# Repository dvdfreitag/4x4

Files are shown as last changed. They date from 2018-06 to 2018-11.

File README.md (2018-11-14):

# 4x4
A 4x4 mechanical keyboard

More or less a clone of https://github.com/di0ib/Misc/tree/master/4x4, but with a different controller. An Arduino Pro Micro instead of an Arduino Micro, they're much easier to get.





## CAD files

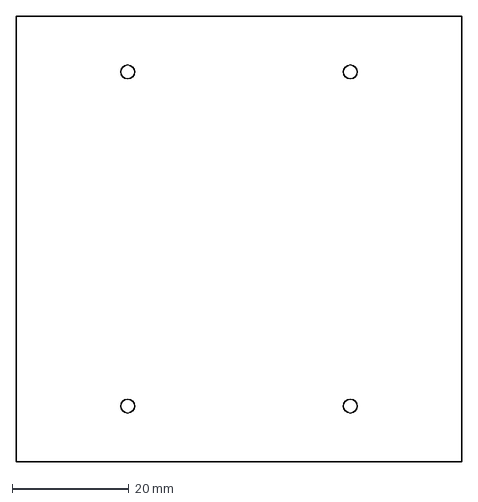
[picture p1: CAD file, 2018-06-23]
4x4-keyboard.dxf
76.2 x 76.2 mm

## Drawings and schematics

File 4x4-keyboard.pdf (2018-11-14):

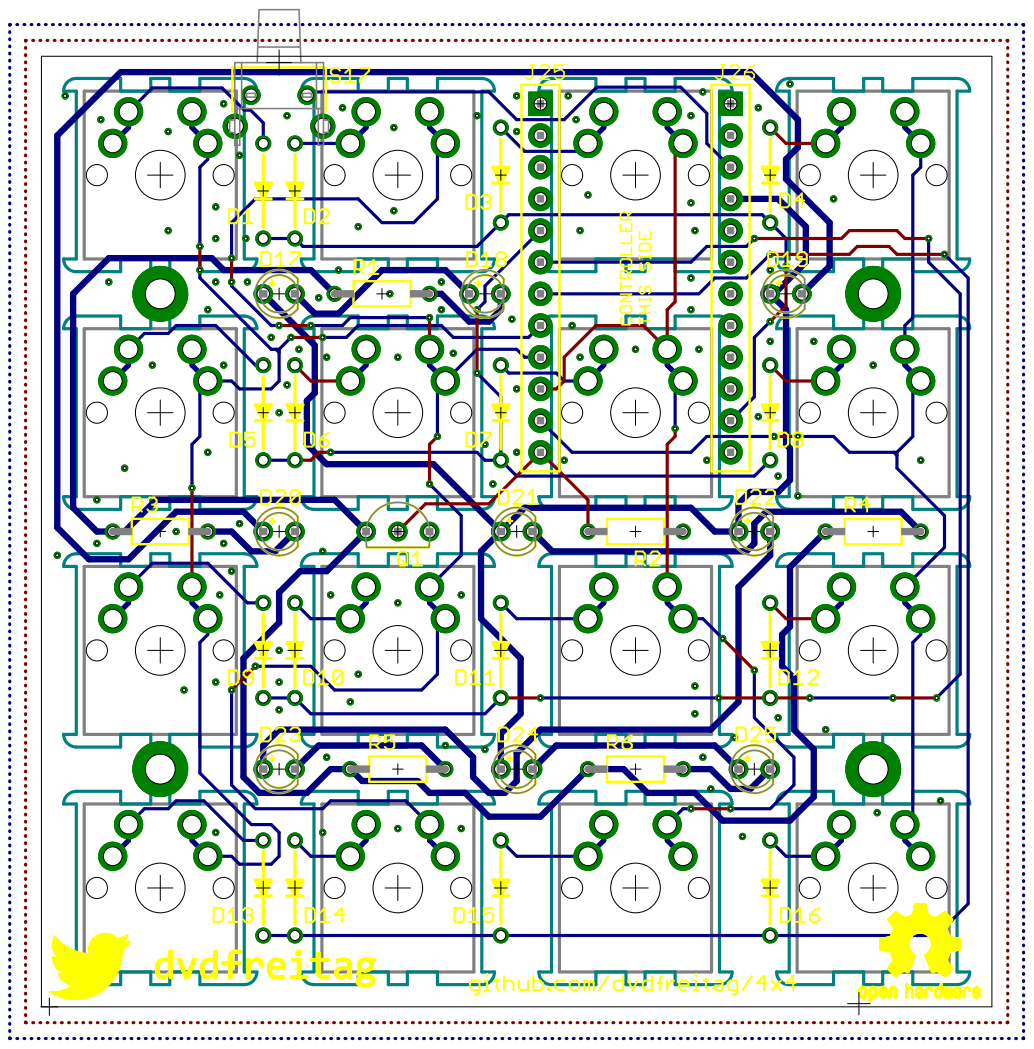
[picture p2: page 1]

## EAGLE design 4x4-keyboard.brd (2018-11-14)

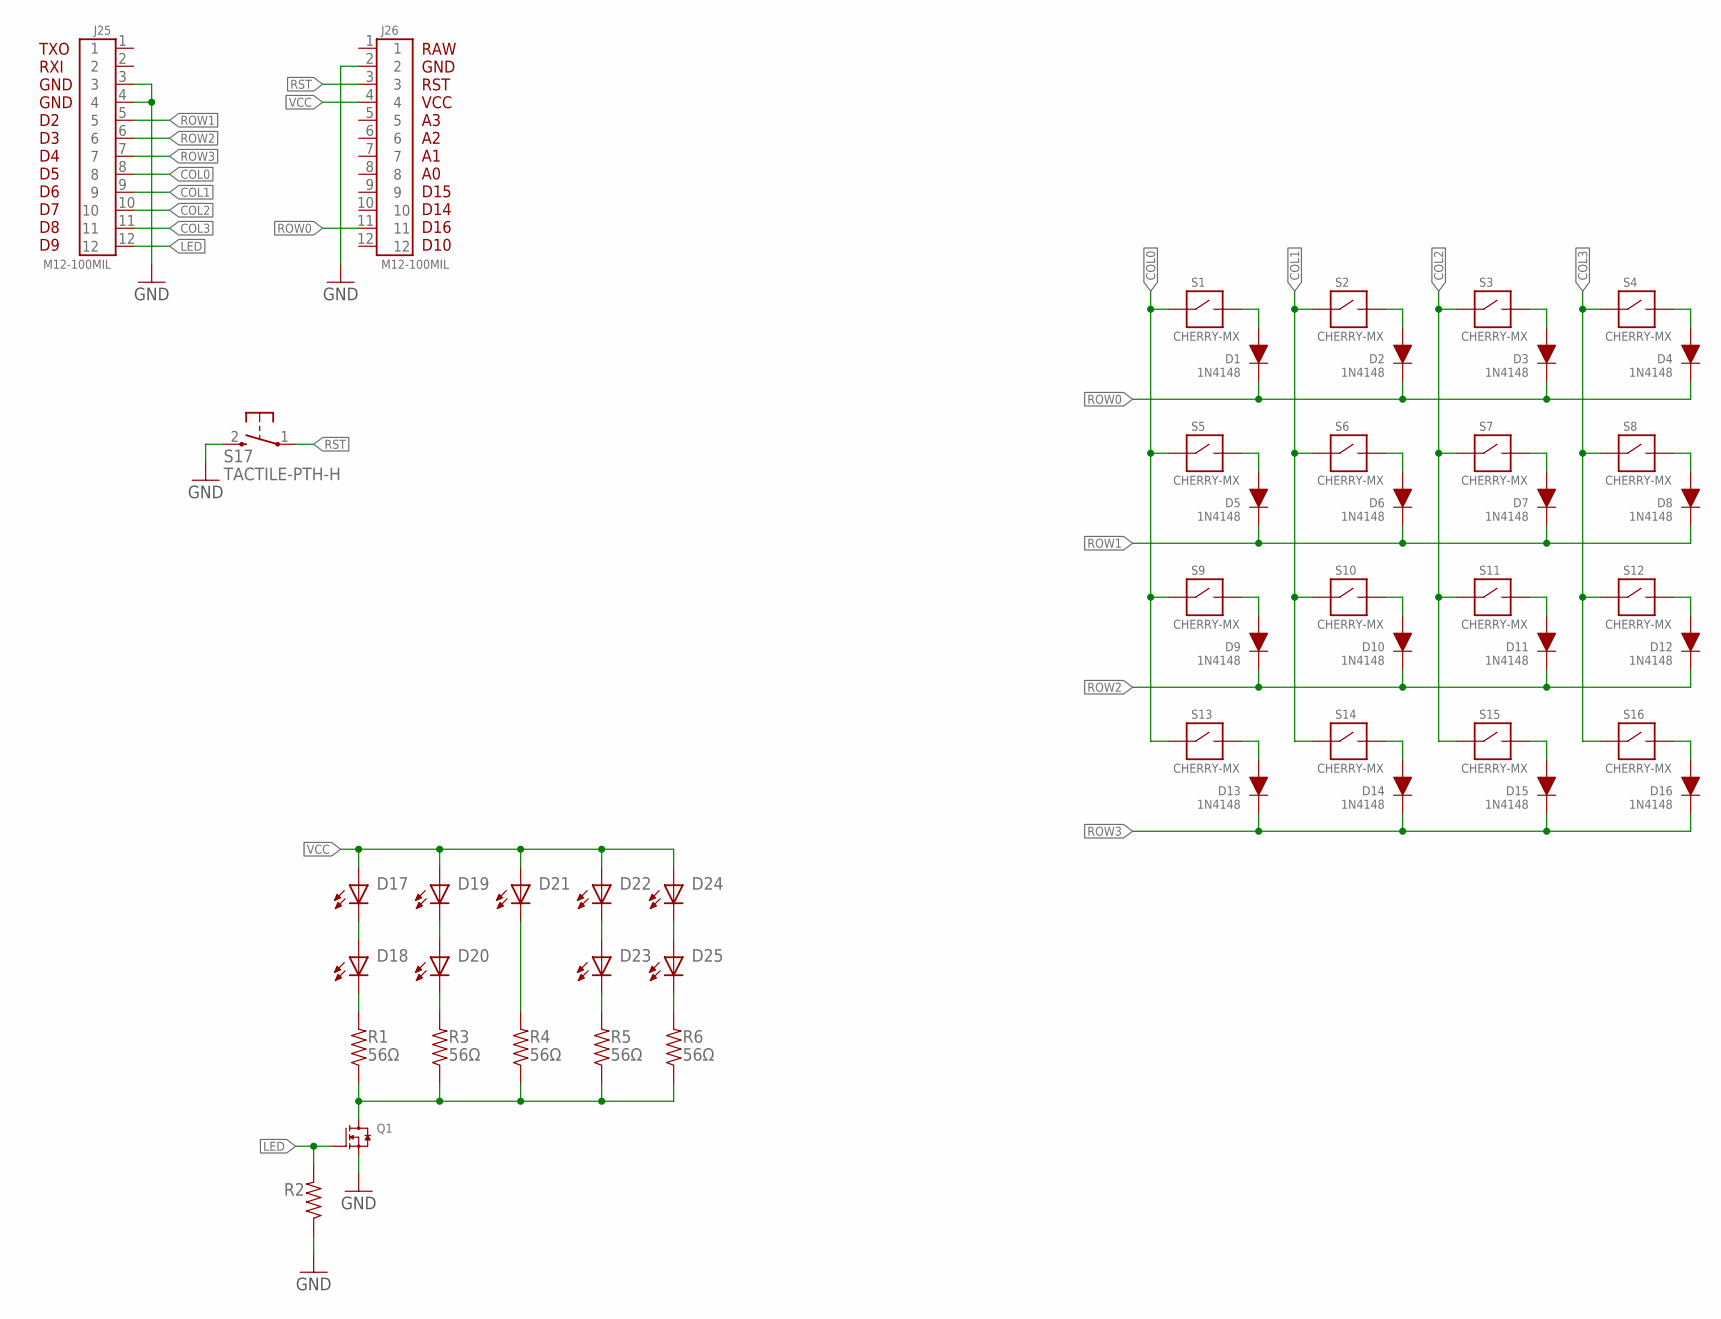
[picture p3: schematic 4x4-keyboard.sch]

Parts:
D1, D2, D3, D4, D5, D6, D7, D8, D9, D10, D11, D12, D13, D14, D15, D16: 1N4148; DIODE-PTH
D17, D18, D19, D20, D21, D22, D23, D24, D25: LED-3MM; 3MM-LED
J25, J26: M12-100MIL; M12X1
Q1: N-MOSFET-TO-92; TO-92-3
R1, R3, R4, R5, R6: 56Ω; RESISTOR-PTH
R2: RESISTOR-PTH
S1, S2, S3, S4, S5, S6, S7, S8, S9, S10, S11, S12, S13, S14, S15, S16: CHERRY-MX
S17: TACTILE-PTH-H; TACTILE-HORIZONTAL

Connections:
COL0: J25.8, S1.S1, S1.S4 (S1), S5.S1, S5.S4 (S1), S9.S1, S9.S4 (S1), S13.S1, S13.S4 (S1)
COL1: J25.9, S2.S1, S2.S4 (S1), S6.S1, S6.S4 (S1), S10.S1, S10.S4 (S1), S14.S1, S14.S4 (S1)
COL2: J25.10, S3.S1, S3.S4 (S1), S7.S1, S7.S4 (S1), S11.S1, S11.S4 (S1), S15.S1, S15.S4 (S1)
COL3: J25.11, S4.S1, S4.S4 (S1), S8.S1, S8.S4 (S1), S12.S1, S12.S4 (S1), S16.S1, S16.S4 (S1)
GND: J25.3, J25.4, J26.2, Q1.1 (SOURCE), R2.P$1 (1), S17.2 (3)
LED: J25.12, Q1.2 (GATE), R2.P$2 (2)
unnamed: D3.A, S3.S2, S3.S3 (S2)
unnamed: D4.A, S4.S2, S4.S3 (S2)
unnamed: D2.A, S2.S2, S2.S3 (S2)
unnamed: D1.A, S1.S2, S1.S3 (S2)
unnamed: Q1.3 (DRAIN), R1.P$1 (1), R3.P$1 (1), R4.P$1 (1), R5.P$1 (1), R6.P$1 (1)
unnamed: D9.A, S9.S2, S9.S3 (S2)
unnamed: D10.A, S10.S2, S10.S3 (S2)
unnamed: D11.A, S11.S2, S11.S3 (S2)
unnamed: D12.A, S12.S2, S12.S3 (S2)
unnamed: D16.A, S16.S2, S16.S3 (S2)
unnamed: D15.A, S15.S2, S15.S3 (S2)
unnamed: D14.A, S14.S2, S14.S3 (S2)
unnamed: D13.A, S13.S2, S13.S3 (S2)
unnamed: D5.A, S5.S2, S5.S3 (S2)
unnamed: D6.A, S6.S2, S6.S3 (S2)
unnamed: D7.A, S7.S2, S7.S3 (S2)
unnamed: D8.A, S8.S2, S8.S3 (S2)
unnamed: D21.C, R4.P$2 (2)
unnamed: D24.C, D25.A
unnamed: D22.C, D23.A
unnamed: D23.C, R5.P$2 (2)
unnamed: D25.C, R6.P$2 (2)
unnamed: D19.C, D20.A
unnamed: D20.C, R3.P$2 (2)
unnamed: D18.C, R1.P$2 (2)
unnamed: D17.C, D18.A
ROW0: D1.C, D2.C, D3.C, D4.C, J26.11
ROW1: D5.C, D6.C, D7.C, D8.C, J25.5
ROW2: D9.C, D10.C, D11.C, D12.C, J25.6
ROW3: D13.C, D14.C, D15.C, D16.C, J25.7
RST: J26.3, S17.1
VCC: D17.A, D19.A, D21.A, D22.A, D24.A, J26.4

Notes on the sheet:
TXO RXI GND GND D2 D3 D4 D5 D6 D7 D8 D9
RAW GND RST VCC A3 A2 A1 A0 D15 D14 D16 D10

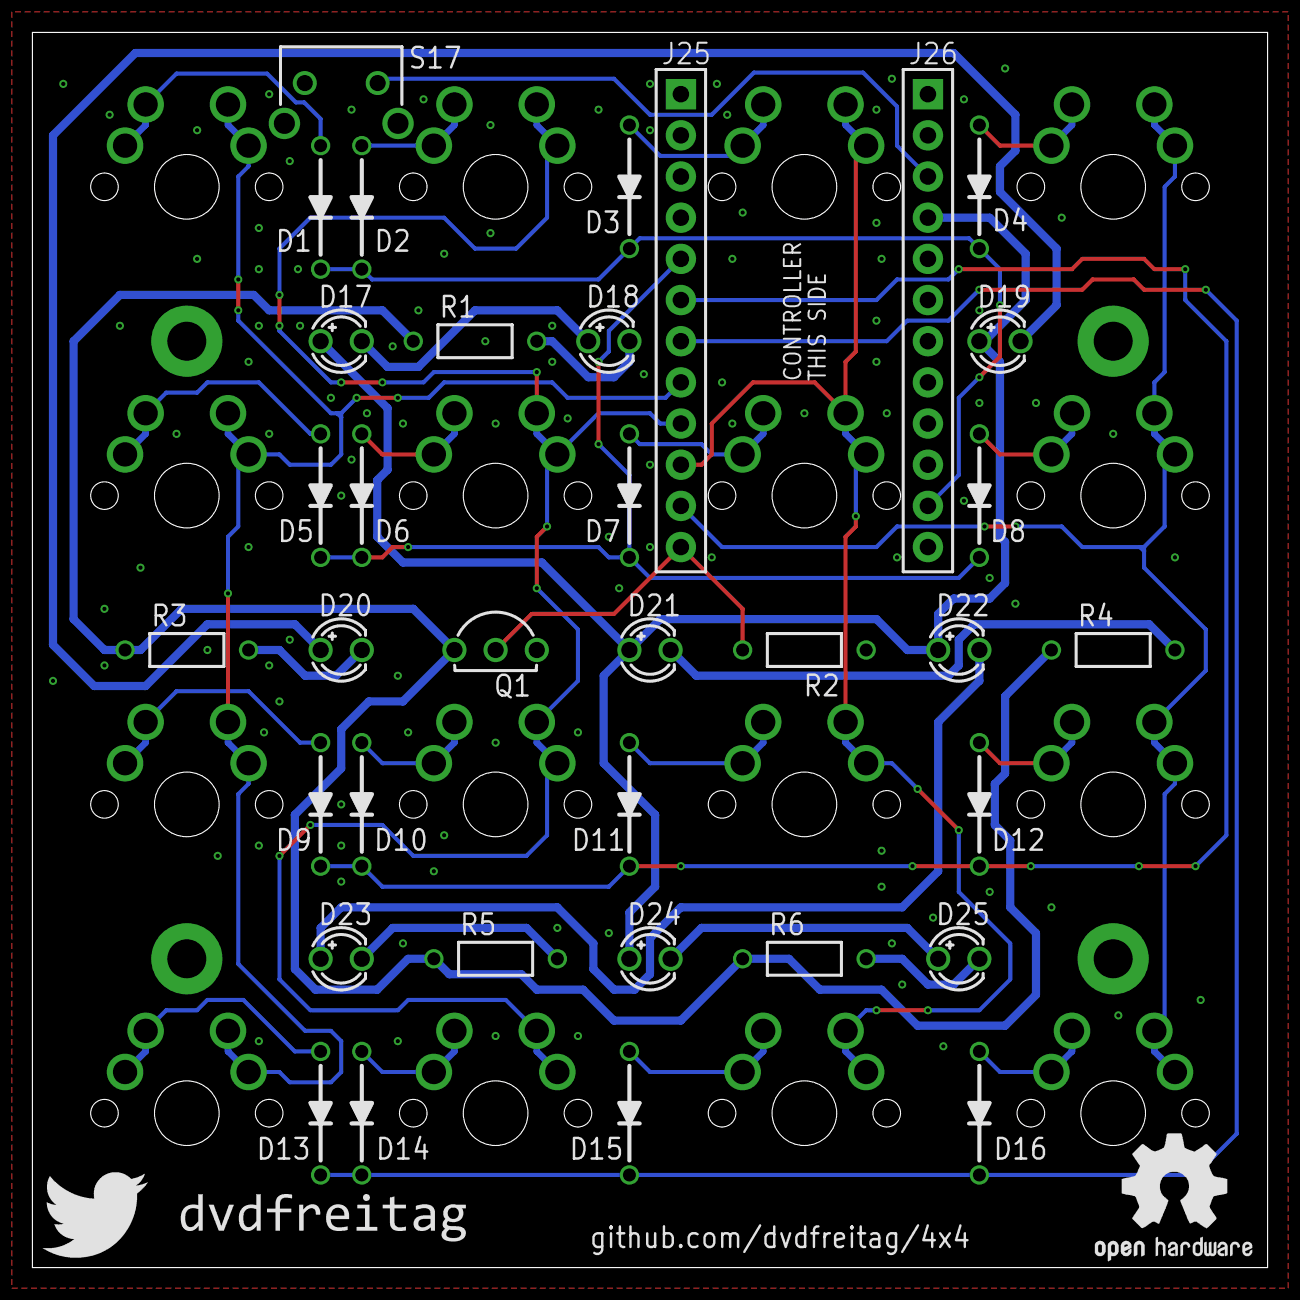
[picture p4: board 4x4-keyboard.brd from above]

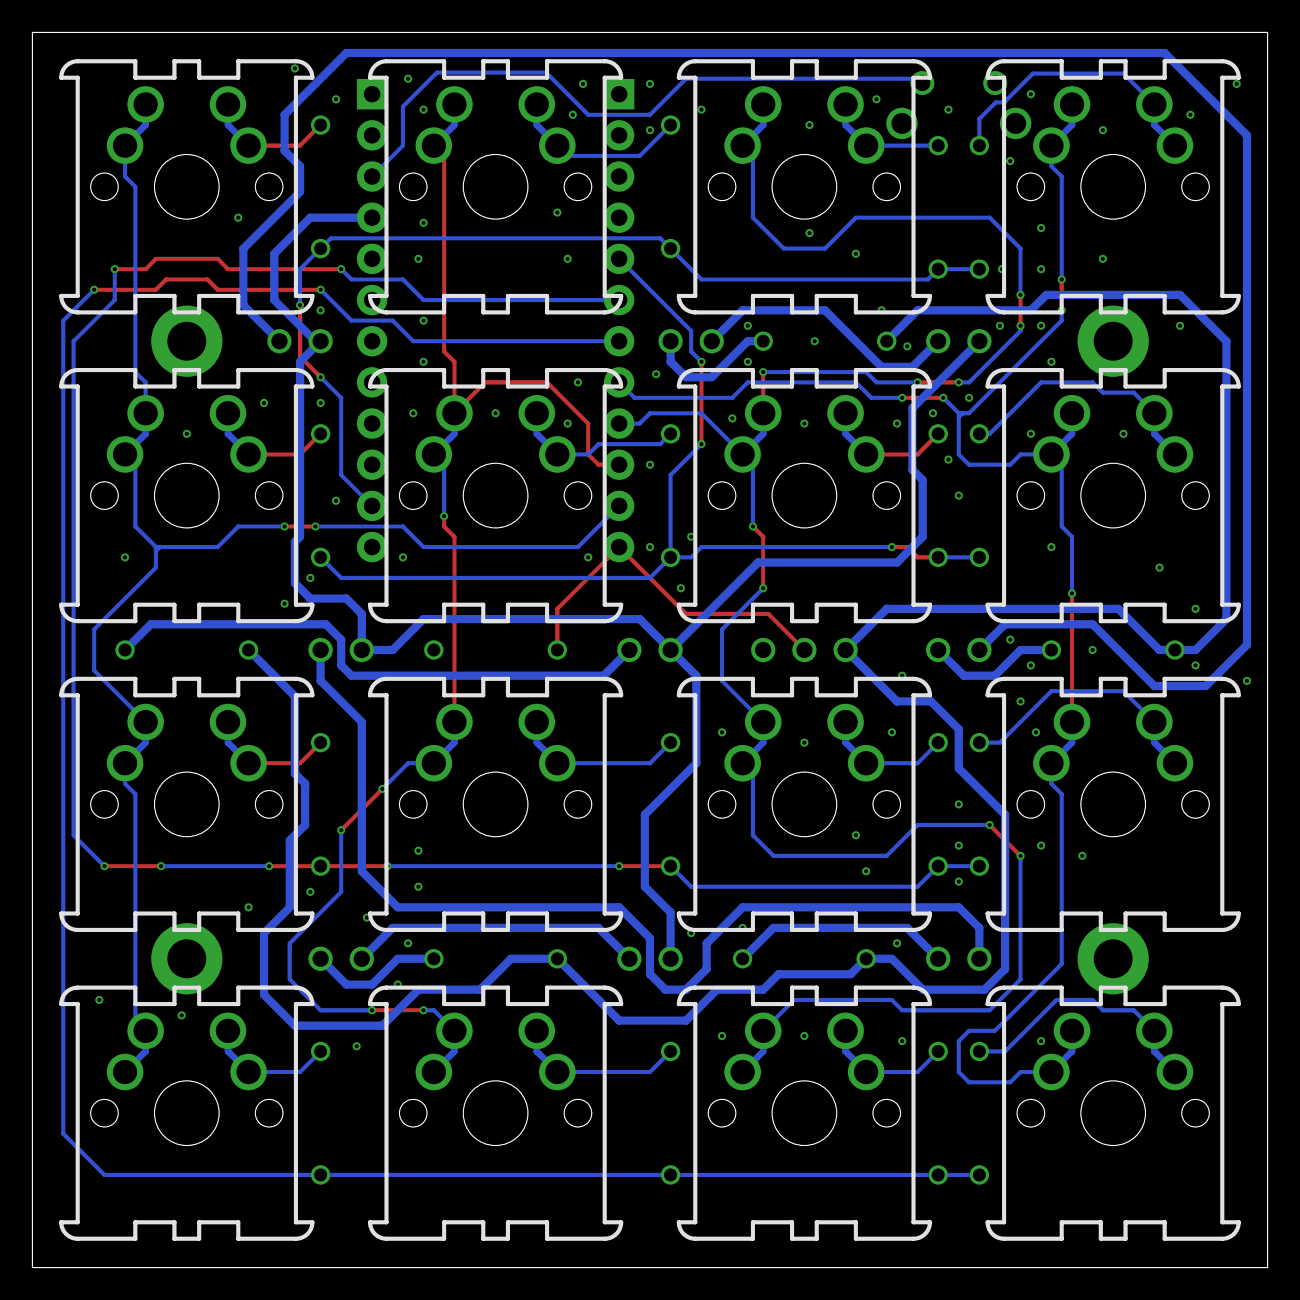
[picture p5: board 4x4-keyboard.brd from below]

Board: 2 copper layers, 76.2 x 76.2 mm, 53 parts (16 on the bottom side), 38 nets.

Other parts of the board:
U$1: TWITTER
U$2: OSHW

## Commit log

2018-06-23 Add drawings
    Add dimensional drawing and dxf for laser cutting
    [4x4-keyboard.dxf]
2018-11-14 Update layout
    - Remove extensible connectors
    - Add backlight 3mm leds instead of frontlight smd
    - Add I/O-controlled mosfet for driving dimmable backlight
    - Add reset switch
    [4x4-keyboard.brd, 4x4-keyboard.sch]
